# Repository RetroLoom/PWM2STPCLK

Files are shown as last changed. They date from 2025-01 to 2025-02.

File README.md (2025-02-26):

# PWM2STPCLK
Vintage CPU throttle adapter designed for use with interchangable PWM controllers. 

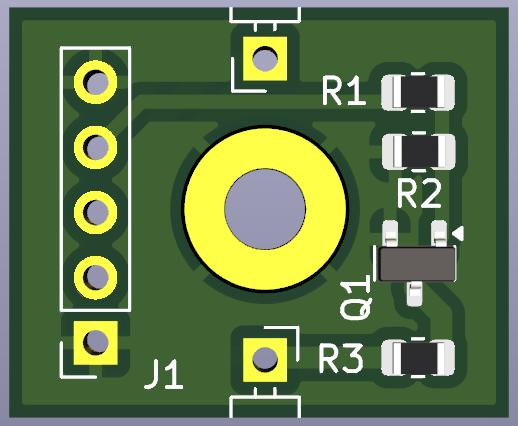
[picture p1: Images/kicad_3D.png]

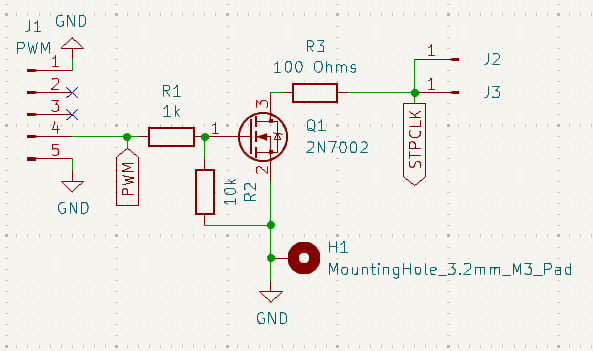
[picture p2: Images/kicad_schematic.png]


This project is inspired from the ThrottleBlaster project from Scrap Computing.

https://github.com/scrapcomputing/ThrottleBlaster

The PWM2STPCLK can mount directly to an ATX motherboard stand-off for direct chassis grounding and securing. This allows placement of the STPCLK pin wiring to be close to CPU and guarded from strain. A standard PWM fan controller can be used for simplicity, but plans for developing dedicated controllers and adapting the ThrottleBlaster is on-going. 






## Build of Materials
https://github.com/RetroLoom/PWM2STPCLK/blob/master/KiCad/PWM2STPCLK.csv

Example PWM Controller - https://www.aliexpress.us/item/3256805787442361.html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

Example PWM Cables - https://www.aliexpress.us/item/3256805588566722.html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

## Support the Developer
This project is brought to you free and open source, but it is not free to develop. If you like this project please consider supporting this and future developments. 

https://www.patreon.com/RetroLoom

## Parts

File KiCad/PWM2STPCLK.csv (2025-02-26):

Id | Designator | Footprint | Quantity | Designation
1 | J2 J3 | PinHeader_1x01_P2.54mm_Horizontal | 2 | STPCLK
2 | R1 | R_0805_2012Metric | 1 | 1k
3 | J1 | PinSocket_1x05_P2.54mm_Vertical | 1 | PWM
4 | R2 | R_0805_2012Metric | 1 | 10k
5 | R3 | R_0805_2012Metric | 1 | 100 Ohms
6 | Q1 | SOT-23 | 1 | 2N7002

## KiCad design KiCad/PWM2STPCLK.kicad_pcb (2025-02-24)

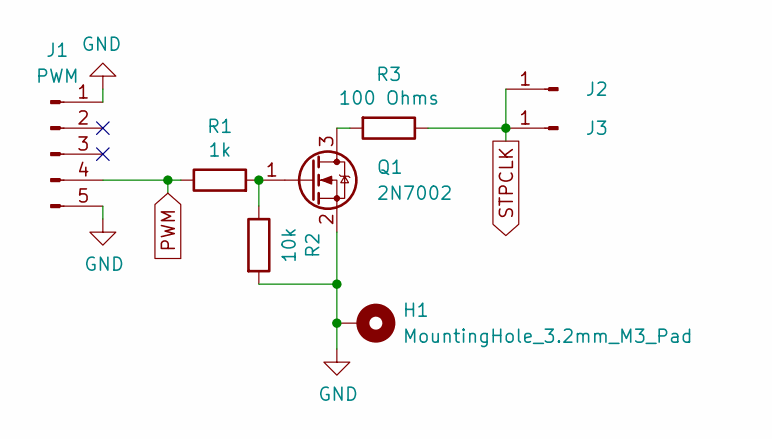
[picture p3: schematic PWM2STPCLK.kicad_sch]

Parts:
H1: MountingHole_3.2mm_M3_Pad
J1: PWM; PinSocket_1x05_P2.54mm_Vertical
J2, J3: STPCLK; PinHeader_1x01_P2.54mm_Horizontal
Q1: 2N7002; SOT-23
R1: 1k; R_0805_2012Metric
R2: 10k; R_0805_2012Metric
R3: 100 Ohms; R_0805_2012Metric

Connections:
GND: H1.1, J1.1, J1.5, Q1.2 (S), R2.2
unnamed: Q1.3 (D), R3.2
unnamed: Q1.1 (G), R1.2, R2.1
PWM: J1.4, R1.1
STPCLK: J2.1, J3.1, R3.1

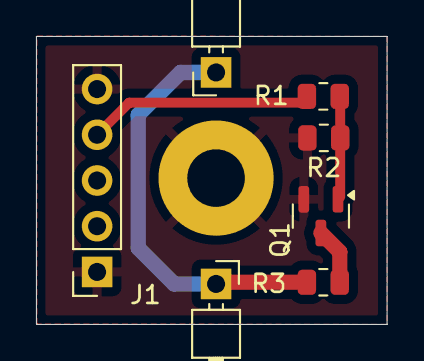
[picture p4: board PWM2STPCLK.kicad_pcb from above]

Board: 2 copper layers, 19.5 x 16.0 mm, 8 parts (0 on the bottom side), 5 nets.

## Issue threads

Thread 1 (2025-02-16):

Switching Noise / Ground loops

RetroLoom, 2025-02-16:
The current version 0.1 generates a substantial amount of switching noise when in use. This is probably caused from there being two different ground sources, or there is current feeding back through the ground channel to the PWM controller and components. The idea behind using a grounding pad on the PWM2STPCLK connecting to the chassis was so that the MOSFET could offload the current from STPCLK to a low resistance ground. However this needs to be isolated from the PWM controller. There is also a possibility that there are voltage offsets from this configuration.

This noise is also produced by the ThrottleBlaster, but it is not as pronounced. I think finding a solution will be beneficial for both.

I am considering switching the 2N7002 to a photo-MOSFET instead. This should allow similar switching, but can isolate the STPCLK pin directly to the mounting pad.

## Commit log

2025-01-31 Initial Release
    [PWM2STPCLK.kicad_pcb, PWM2STPCLK.kicad_sch]
2025-02-24 v0.2 - Low resistance ground, cleaner layout
    [PWM2STPCLK.kicad_pcb]
2025-02-26 Fix CSV error
    [PWM2STPCLK.csv]
